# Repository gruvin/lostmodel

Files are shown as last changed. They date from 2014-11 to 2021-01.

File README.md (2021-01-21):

# Open Source RC Lost Model Alarm 
* Two modes -- Normal (manual switch) or Inactivity
* Modes programmable from TX 
* Resonated PIEZO
* LOUD!

Hardware design created in free, open source KiCAD EDA suite.

Employs ATmega88PA (5x5mm MLF) to intelligently drive a quartz piezo via autotransformer at 2.8KHz resonant frequency. This gives air and ear peircingly, LOUD output. Piezo and transformer taken from cheap personal alarm.

The circuit board is 16x33mm and the piezo is 28mm diameter and 3mm thick, including resonance chamber. The autotransformer (11mm height) can be mounted either on the top or bottom of the PCB or off board, if needed for space.

There are three status LEDs. Green, Blue and Red. They do, umm, stuff.

Programming and status tones are emitted (at lower, close range tolerable volume levels!) using Morse code, which I consider better than counting beeps for programming and status reporting.

The alarm can work in either Normal or Inactivity mode.

In Inactivity mode, ear peircing noise is made when there has been no receiver channel activity for a short while. Useful for cases where a dedicated RC channel is not available. Connect to aileron or elevator channel, for example.

Normal mode uses a dedicated receiver channel as a simple on/off switch. (Greater than or lower than mid point.)

## KiCAD v4 PCB Render
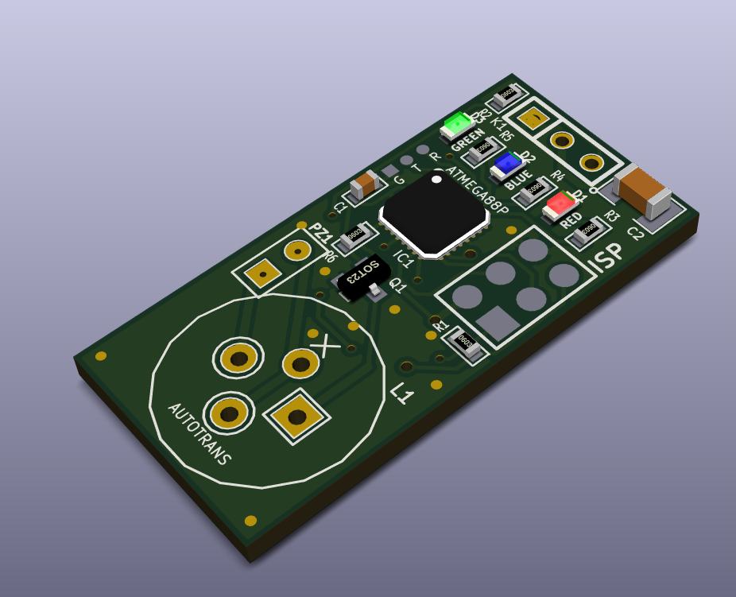
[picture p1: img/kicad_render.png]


Autotransformer and off-board quartz piezo not shown.

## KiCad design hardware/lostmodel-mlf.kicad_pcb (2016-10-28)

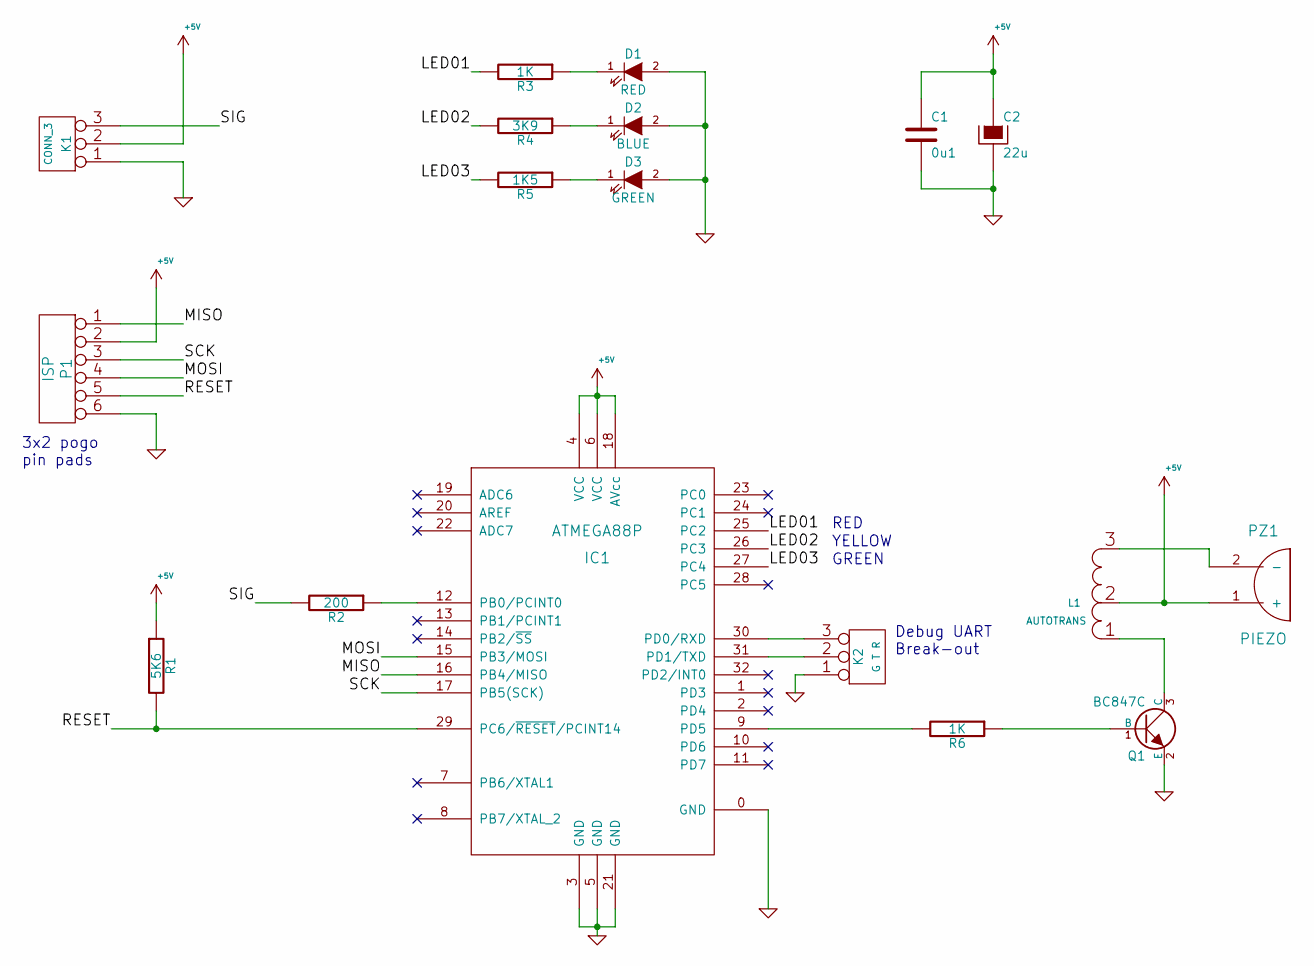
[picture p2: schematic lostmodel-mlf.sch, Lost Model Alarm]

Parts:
C1: 0u1; SM0603_GRUVIN
C2: 22u; SM1210_GRUVIN_POL
D1: RED; LED-0603
D2: BLUE; LED-0603
D3: GREEN; LED-0603
IC1: ATMEGA88P; MLF-32_2mmVIA_SINK
K1: CONN_3; SIL-3
K2: G T R; SIL-3
L1: AUTOTRANS; TRI-3
P1: ISP; PIN_ARRAY_3x2_GRUVIN
PZ1: PIEZO; PIN_ARRAY_2X1
Q1: BC847C; SOT23-BCE
R1: 5K6; SM0603
R2: 200; SM0603
R3, R6: 1K; SM0603
R4: 3K9; SM0603
R5: 1K5; SM0603

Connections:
+5V: C1.1, C2.1, IC1.4 (VCC), IC1.6 (VCC), IC1.18 (AVcc), K1.2 (PM), L1.2, P1.2, PZ1.1 (+), R1.1
/LED01: IC1.25 (PC2), R3.2
/LED02: IC1.26 (PC3), R4.2
/LED03: IC1.27 (PC4), R5.2
/MISO: IC1.16 (PB4/MISO), P1.1
/MOSI: IC1.15 (PB3/MOSI), P1.4
/RESET: IC1.29 (PC6/~RESET~/PCINT14), P1.5, R1.2
/SCK: IC1.17 (PB5(SCK)), P1.3
/SIG: K1.3, R2.2
GND: C1.2, C2.2, D1.2 (A), D2.2 (A), D3.2 (A), IC1.0 (GND), IC1.3 (GND), IC1.5 (GND), IC1.21 (GND), K1.1, K2.1, P1.6, Q1.2 (E)
unnamed: D1.1 (K), R3.1
unnamed: D2.1 (K), R4.1
unnamed: D3.1 (K), R5.1
unnamed: IC1.9 (PD5), R6.2
unnamed: IC1.12 (PB0/PCINT0), R2.1
unnamed: IC1.30 (PD0/RXD), K2.3
unnamed: IC1.31 (PD1/TXD), K2.2 (PM)
unnamed: L1.1, Q1.3 (C)
unnamed: L1.3, PZ1.2 (-)
unnamed: Q1.1 (B), R6.1

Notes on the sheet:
3x2 pogo pin pads
RED
YELLOW
GREEN
Debug UART Break-out

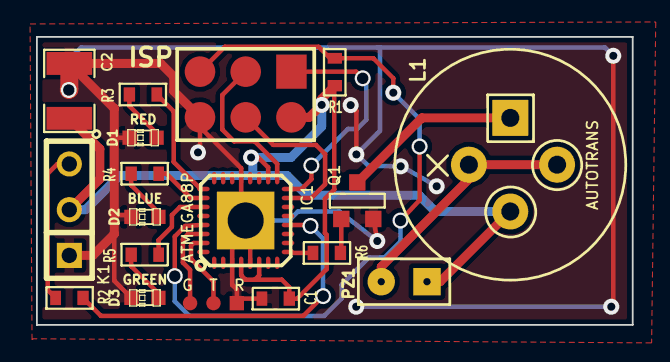
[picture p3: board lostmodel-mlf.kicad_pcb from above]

Board: 2 copper layers, 33.1 x 16.0 mm, 18 parts (0 on the bottom side), 20 nets.

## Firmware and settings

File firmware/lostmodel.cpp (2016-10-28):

/* Filename: lostmodel.cpp
 * Project: Lost Model Alarm for AVR ATmega88P
 * Author: Bryan Rentoul (aka Gruvin)
 * Creation Date: 2014-11-22
 * Tabsize: 2
 * Copyright: (c) 2014 Gruvin9X Project and Bryan J. Rentoul aka Gruvin
 * License: GNU GPL v3 (see License.txt)
 * This Revision: $Id$
 *
 * This file is part of Gruvin9X Lost Model Alarm.
 *
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
 * You should have received a copy of the GNU General Public License
 * along with this program in the file Lincese.txt.  If not, please
 * see <http://www.gnu.org/licenses/>
 */

#include <avr/io.h>
#include <avr/pgmspace.h>
#include <avr/eeprom.h>
#include <avr/wdt.h>
#include <avr/interrupt.h>
#include <util/delay.h>
#include <stdlib.h> // abs()
#include "lostmodel.h"

void beeperOn()
{
  LED_ON(3);

  // PWM ON
  TCCR0A |= (0b10<<COM0B0);
}

void beeperOff()
{
  LED_OFF(3);

  TCCR0A &= ~(0b11<<COM0B0);
}

const unsigned char morseTable[47] PROGMEM = {
  0b11110011, // , ASCII 44(dec)
  0,
  0b11010101, // .
  0b10110010, // /
  0b10111111, // 0
  0b10101111, // 1
  0b10100111, // 2
  0b10100011, // 3
  0b10100001, // 4
  0b10100000, // 5
  0b10110000, // 6
  0b10111000, // 7
  0b10111100, // 8
  0b10111110, // 9
  0,          // :
  0,          // ;
  0,          // <
  0b10110001, // =
  0,          // >
  0b11001100, // ?
  0,          // @
  0b01001000, // A
  0b10010000, // B
  0b10010100, // C
  0b01110000, // D
  0b00100000, // E
  0b10000100, // F
  0b01111000, // G
  0b10000000, // H
  0b01000000, // I
  0b10001110, // J
  0b01110100, // K
  0b10001000, // L
  0b01011000, // M
  0b01010000, // N
  0b01111100, // O
  0b10001100, // P
  0b10011010, // Q
  0b01101000, // R
  0b01100000, // S
  0b00110000, // T
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
}; // morse table


enum morseState_t { 
  END = 0,
  DIT,
  DAH,
  BITGAP,
  LETTERGAP,
  SPACE,
  NEXTBIT,
  NEXTCHAR,
  START,
  STOP
} morseState = STOP;

char *morseString;
// morse for LM - di'dah'di'dit, dah dah (lost model)
static inline void morseStateMachine() 
{
  static unsigned int timer;
  static unsigned char bitCount;
  static unsigned char letterBits;
  static unsigned char charIndex;
  static char thisChar;

  switch (morseState)
  {
    case DIT:
      if (timer == 0)
        beeperOn();
      if (++timer > DITLENGTH) 
      {
        timer = 0;
        morseState = BITGAP;
      }
      break;

    case DAH:
      if (timer == 0)
        beeperOn();
      if (++timer > DITLENGTH * 3)
      {
        timer = 0;
        morseState = BITGAP;
      }
      break;

    case BITGAP:
      if (timer == 0) 
        beeperOff();
      if (++timer > DITLENGTH) morseState = NEXTBIT;
      break;

    case LETTERGAP:
      if (timer == 0) 
        beeperOff();
      if (++timer > DITLENGTH * 2) morseState = NEXTCHAR;
      break;

    case SPACE:
      if (timer == 0) 
        beeperOff();
      if (++timer > DITLENGTH * 6) morseState = NEXTCHAR;
      break;

    case NEXTBIT:

      timer = 0;

      if (letterBits & 0b10000000)
        morseState = DAH;
      else
        morseState = DIT;

      letterBits <<= 1; // shift bits left 1 position
      if (bitCount-- == 0)
        morseState = LETTERGAP;

      break;

    case NEXTCHAR:

      thisChar = pgm_read_byte(&morseString[charIndex++]);

      if (thisChar == ' ') 
      {
        timer = 0;
        morseState = SPACE;
      }
      else if ( (thisChar == '\0') || (thisChar < ',') || (thisChar > 'Z') ) // end of string or invalid character?  
        morseState = STOP;
      else
      {
        letterBits = pgm_read_byte(&morseTable[thisChar-44]);
        bitCount = (letterBits >> 5);
        if (bitCount < 6)
          letterBits <<= 3;
        else
          letterBits <<= 2;

        morseState = NEXTBIT;
      }
      break;


    case START:
      beeperOff();
      timer = 0;
      charIndex = 0;
      morseState = NEXTCHAR;
      break;

    case STOP:
      break; // do nothing

    default:
      morseState = STOP;
      break;

  } // switch
      
}


#define PULSE_INVALID (-1)
volatile int sigPulseWidth;
volatile unsigned int pulseTimeoutCounter = 0;
volatile bool runningIndicatorEnabled = false;
// this ISR called every 250uS
ISR(TIMER2_COMPA_vect)
{
  if (pulseTimeoutCounter++ > PULSE_TIMEOUT)
  {
    sigPulseWidth = PULSE_INVALID;  // signal no pulse detected
    pulseTimeoutCounter--; // prevent counter incrementing further
  }

  static unsigned char count = 0;
  if ((count++ % 4) == 3)  // call the Morse state machine every 1 millisecond 
    morseStateMachine();

  // blink middle (blue) LED briefly, each three seconds to indicate RUNNING state (if so)
  static unsigned int runningIndicatorCount = 0;
  if (runningIndicatorEnabled)
  {
    if (runningIndicatorCount == 0) LED_ON(2);
    else if (runningIndicatorCount == (4 * 120)) LED_OFF(2);  // LED on for 120ms

    if (runningIndicatorCount == (4 * 3000 - 1)) // reset counter at 3 seconds
      runningIndicatorCount = 0;
    else
      runningIndicatorCount++;
  }
  else 
    LED_OFF(2);

}

ISR(TIMER1_CAPT_vect)
{
  // an edge detection event has occured on the ICP1(PB0) pin
  unsigned int icr;

  icr = ICR1; // capture counter value as at this edge trigger

  if (TCCR1B & (1<<ICES1)) // trigger was high going edge
  {
    TCNT1 = 0;             // reset counter
    TCCR1B &= ~(1<<ICES1); // set next trigger to low going edge
  }
  else // trigger was low going edge
  {
    if ((icr > 800) && (icr < 2200)) 
    {
      pulseTimeoutCounter = 0;
      sigPulseWidth = icr;
    }
    else
    {
      sigPulseWidth = PULSE_INVALID; // invalid pulse width
    }
    TCCR1B |= (1<<ICES1); // set next trigger to high going edge
  }

}

void morseStart()
{
  if (morseState != STOP) return;
  morseState = START;
}

void morseStop()
{
  morseState = STOP;
  beeperOff();
}

void storeRunMode(unsigned char newmode)
{
  eeprom_write_byte(0x00, newmode);
}

int main(void)
{
  enum { INIT = 0, WAIT_READY, READY, RUNNING, PROGRAM } runState = INIT;
  enum runMode_t { NORMAL = 0, INACTIVITY } runMode = NORMAL;

  /**************************
   ****  STATE MACHINE   ****
   **************************/
  while (1)
  {

    runningIndicatorEnabled = (runState == RUNNING) ? true : false;
    switch (runState) 
    {
      case INIT: 
      {
        cli();
        wdt_reset();

        wdt_enable(WDTO_4S);  // 4 second watchdog timer. (Brown Out Detector fuses are set for 2.7V)

        LED1_DDR |= (1<<LED1_BIT); LED1_PORT &= ~(1<<LED1_BIT);     // output
        LED2_DDR |= (1<<LED2_BIT); LED2_PORT &= ~(1<<LED2_BIT);     // output
        LED3_DDR |= (1<<LED3_BIT); LED3_PORT &= ~(1<<LED3_BIT);     // output
        PIEZO_DDR |= (1<<PIEZO_BIT); PIEZO_PORT &= ~(1<<PIEZO_BIT); // output (PWM on timer 0)
        SIG_DDR &= ~(1<<SIG_BIT); SIG_PORT |= (1<<SIG_BIT);         // input with pullup (ICR1)

        // set up PWM output on OC0B pin (timer 0)
        TCCR0A = (0b01<<WGM00); // 8-bit Phase Correct PWM mode, output on OC0B (PD5) ...
        TCCR0B = (1<<WGM02) | (0b010<<CS00); // ... clk/8 with TOP(OCR0A)=180 / 2 gives ~2.8KHz

        // start piezo tone out at a lower, quieter frequency and duty cycle
        OCR0A = 255; 
        OCR0B = PWM_DUTY_CYCLE_QUIET;

        // set up timer 1 for input capture compare on ICP1 pin (PB0, IC pin 12)
        TCCR1A = (0b00<<WGM10);
        TCCR1B = (0b010<<CS10); // clk/8 for 1MHz counting
        TCCR1B |= (1<<ICES1);   // trugger on rising edge (initially)
        TCNT1 = 0;
        sigPulseWidth = PULSE_INVALID; 
        TIMSK1 = (1<<ICIE1);    // input capture interrupt enabled

        // set up timer 2 for the Morse code sate machine
        TCCR2A = (0x10<<WGM20); // CTC mode
        TCCR2B = (0b010<<CS20); // CLK / 8 (1Mhz counter rate)
        TCNT2 = 0;
        OCR2A = 249;            // counter TOP (250uS, 8-bit timer)
        TIMSK2 = (1<<OCIE2A);   // enable timer 2 OC interrupt (every 1ms) 
        
        sei(); // gloabl interrupt enable

        // retrieve stored Run Mode from EEPROM
        runMode = (enum runMode_t)eeprom_read_byte(0x00);
        if (runMode > INACTIVITY) // sanitize
        {
          runMode = NORMAL;
          storeRunMode(runMode);
        }

        _delay_ms(1000);             // allow one second for the receiver to boot up
        unsigned int pulseSum = 0;
        unsigned int lastPW = 0;
        int count;
        for (count = 0; count < 10; count++)
        {
          int thisPulse = sigPulseWidth;
          if (lastPW == 0) lastPW = thisPulse;
          if (thisPulse > 0)
          {
            pulseSum += abs(thisPulse - lastPW);
            lastPW = thisPulse;
          }
          _delay_ms(50);
        }
        if ((pulseSum / count) > 200) // enter programming mode if average pulse delta large enough 
        {
          runState = PROGRAM;
          break;
        }
        runState = WAIT_READY;
        break;
      }

      case WAIT_READY: 
      {
        LED_ON(1);

        if ((sigPulseWidth < 0) && (morseState == STOP))
        {
          morseString = (char *)PSTR("E   ");
          morseStart();
        }
        else if (morseState == STOP)
        {
          LED_OFF(1);
          if (runMode == NORMAL)
            morseString = (char *)PSTR("R N ");
          else
            morseString = (char *)PSTR("R I ");
          morseStart();
          runState = READY;
        }
        break;
      }

      case READY:
      {
        if (morseState == STOP)
        {
          // Set beeper frqeuency to ~2.8KHz at 15% duty cycle = LOUD!
          OCR0A = 180;
          OCR0B = PWM_DUTY_CYCLE;

          // emit a single, loud "BIP!"
          if (sigPulseWidth < MIDPOINT)
          {
            beeperOn();
            _delay_ms(100);
            beeperOff();
          }

          runState = RUNNING;
        }
        break;
      }

      case RUNNING: 
      {
        switch (runMode)
        {
          case NORMAL: /* manually switched at transmitter */
          {
            if (sigPulseWidth > 0)
            {
              if (sigPulseWidth > MIDPOINT)
              {
                morseString = (char *)PSTR("LOST "); 
                morseStart();    // start bleeting loud morse tones
              }
              else
                morseStop();
            } 
            else
            {
              morseStop();
              runState = WAIT_READY; // we lost the pulse signal TODO: should optionally alarm instead?
            }
          
            break;
          }

          case INACTIVITY: /* enteres lost mode if no acitivity seen for a while */
          {
            static int last_sigPulseWidth = 0;
            static int last_sigPulseWidthAverage = 0;
            static int sigPulseWidthAverage;
            static unsigned int inactiveTimer = 0;
            
            if (sigPulseWidth > 0) // if pulse has not timed out
            {
              int thisPulse = sigPulseWidth;
              if (last_sigPulseWidth == 0) last_sigPulseWidth = thisPulse;
              sigPulseWidthAverage = ((last_sigPulseWidth * 7) + thisPulse) / 8; // some noise filtering
              last_sigPulseWidth = thisPulse;

              if (last_sigPulseWidthAverage == 0)
                last_sigPulseWidthAverage = sigPulseWidthAverage;

              if ( (sigPulseWidthAverage > (last_sigPulseWidthAverage-20)) 
                  && (sigPulseWidthAverage < (last_sigPulseWidthAverage+20/*TODO sensitivity*/)) )
              {
                if (inactiveTimer++ > 600/*TODO -- how long to wait for inactivity before alarming*/)
                {
                  inactiveTimer--; // don't let this keep climbing
                  if (morseState == STOP)
                  {
                    morseString = (char *)PSTR("LOST "); 
                    morseStart();   // start bleeting loud morse tones
                  }
                }
              }
              else
              {
                inactiveTimer = 0;
                morseStop();
              }
              last_sigPulseWidthAverage = sigPulseWidthAverage;

            }
            else
            {
              morseStop();
              runState = WAIT_READY; // we lost the signal entirely. Go quiet.
            }

          }
        }

        break; // case RUNNING
      }

      case PROGRAM: 
      {
        static enum { 
          WAIT, // wait for pulse to go above MIDPOINT before entering program mode
          ENTER, 
          ASK_NORMAL, 
          ANS_NORMAL, 
          ASK_INACTIVE, 
          ANS_INACTIVE, 
          OK, 
          EXIT 
        } pgmState = WAIT;
        static int pgmTimer = 0;


        switch (pgmState)
        {
          case WAIT:
            if (sigPulseWidth < (MIDPOINT * 1.17)) // at least 3/4 stick needed (allowing for first 1ms being included)
            { 
              if (morseState == STOP)
              {
                LED_TOGGLE(2);
                morseString = (char *)PSTR("W  ");
                morseStart();
              }
            }
            else if (pgmTimer++ > 100)
            {
              pgmTimer = 0;
              morseStop();
              pgmState = ENTER;
            }
            break;

          case ENTER:
            LED_ON(1);
            morseString = (char *)PSTR("P  ");
            morseStart();
            pgmState = ASK_NORMAL;
            break;

          case ASK_NORMAL:
            if (morseState == STOP) // wait for morse code to finish sounding
            {
              pgmTimer = 0;
              morseString = (char *)PSTR("N? ");
              morseStart();
              pgmState = ANS_NORMAL;
            }
            break;

          case ANS_NORMAL:
            if (morseState == STOP) // wait for morse code to finish sounding
            {
              if (pgmTimer++ < 200) // did they say yes?
              {
                if (sigPulseWidth < MIDPOINT)
                {
                  storeRunMode(NORMAL);
                  pgmState = OK;
                }
              } else
                pgmState = ASK_INACTIVE;
            }
            break;

          case ASK_INACTIVE:
            if (morseState == STOP) // wait for morse code to finish sounding
            {
              pgmTimer = 0;
              morseString = (char *)PSTR("I? ");
              morseStart();
              pgmState = ANS_INACTIVE;
            }
            break;

          case ANS_INACTIVE:
            if (morseState == STOP) // wait for morse code to finish sounding
            {
              if (pgmTimer++ < 200) // did they say yes?
              {
                if (sigPulseWidth < MIDPOINT)
                {
                  storeRunMode(INACTIVITY);
                  pgmState = OK;
                }
              } else
                pgmState = ASK_NORMAL;
            }
            break;

          case OK:
            morseString = (char *)PSTR("OK ");
            morseStart();
            pgmState = EXIT;
            break;

          case EXIT:
            if (morseState == STOP) // wait for morse code to finish sounding
              runState = INIT;
            break;
        }

        break;
      }

      default:
        runState = INIT;

    } // FSM switch

    _delay_ms(10); // XXX TODO: fix this ugly hack,  here just to slow down asynch counters for PROGRAM and INACTIVITY modes

    wdt_reset();
  } // MAIN LOOP
}

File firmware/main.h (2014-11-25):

#ifndef _MAIN_H
#define _MAIN_H

#define DEBUG 1

// CW dit length (arbitrary units)
#define DITLENGTH 8 // arbitrary while morseStateMachine is just part of the main loop

// TODO: prototype version. Pins changed for production version ...
//       These are NOT the pins specified in the production electronic schematic
#define SIG_INP   PIND
#define SIG_PORT  PORTD
#define SIG_DDR   DDRD
#define SIG_BIT   3 // D-

#define PIEZO_PORT PORTD
#define PIEZO_DDR  DDRD
#define PIEZO_BIT  5 // LED01

#define LED1_PORT PORTC
#define LED1_DDR  DDRC
#define LED1_BIT  3 // LED05 (not used in prototype)

#define LED2_PORT PORTD
#define LED2_DDR  DDRD
#define LED2_BIT  4 // LED02

#define LED3_PORT PORTC
#define LED3_DDR  DDRC
#define LED3_BIT  5 // LED03

#define LED_ON(a) LED ## a ## _PORT |= (1<<LED ## a ## _BIT)
#define LED_OFF(a) LED ## a ## _PORT &= ~(1<<LED ## a ## _BIT)

// input pulse width measurement
// CLK = 8MHz
// timing loop is 9 cycles
// time for one cycle = 1 / (8,000,000 / 9) = 1.125uS
// 1500uS / 1.125 ~= 1333 
#define MIDPOINT 1350 // value from actual tests

// PWM piezo output volume
#ifdef DEBUG
#define PWM_DUTY_CYCLE 3
#else
#define PWM_DUTY_CYCLE 27
#endif
#define PWM_DUTY_CYCLE_QUIET 2

#define true (-1)
#define false 0

// Run Modes
#define NORMAL 0
#define INACTIVITY 1



#endif

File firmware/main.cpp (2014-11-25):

/* Name: main.c
 * Project: Lost Model Alarm for AVR ATmega88P
 * Author: Bryan Rentoul (aka Gruvin)
 * Creation Date: 2014-11-22
 * Tabsize: 2
 * Copyright: (c) 2014 Gruvin9X Project and Bryan J. Rentoul aka Gruvin
 * License: GNU GPL v2 (see License.txt)
 * This Revision: $Id$
 */

#include <avr/io.h>
#include <avr/pgmspace.h>
#include <avr/eeprom.h>
#include <avr/wdt.h>
#include <util/delay.h>
#include <stdlib.h> // abs()
#include "main.h"

int pulseInWidth()
{
  unsigned int width;         // pulse width in while loop iterations, which should be exactly 10 clock cycles
  unsigned long numloops;
  
  numloops = 0;
  // wait for any previous pulse to end
  while (SIG_INP & (1<<SIG_BIT))
    if (numloops++ > (MIDPOINT * 2)) return -1;

  // wait for pulse to start
  while (!(SIG_INP & (1<<SIG_BIT)))
    if (numloops++ > ((unsigned long)MIDPOINT * 14)) return -1; // MIDPOINT ~= 1500us. Full PPM sweep over 8 channels is 23ms.

  // wait for pulse to end
  width = 0;
  while (SIG_INP & (1<<SIG_BIT))
    if (width++ > (MIDPOINT * 3)) return -1;

  return width; 
}

void beeperOn()
{
  LED_ON(2);

  // PWM ON
  TCCR0A |= (0b10<<COM0B0);
}

void beeperOff()
{
  LED_OFF(2);

  TCCR0A &= ~(0b11<<COM0B0);
}

const char morse[47][7] PROGMEM  = {
  { 2, 2, 1, 1, 2, 2, 0 },// , ASCII = 44
  { 0 },                  // -
  { 1, 2, 1, 2, 1, 2, 0}, // .
  { 2, 1, 1, 2, 1, 0 },   // /
  { 2, 2, 2, 2, 2, 0 },   // 0
  { 1, 2, 2, 2, 2, 0 },   // 1
  { 1, 1, 2, 2, 2, 0 },   // 2
  { 1, 1, 1, 2, 2, 0 },   // 3
  { 1, 1, 1, 1, 2, 0 },   // 4
  { 1, 1, 1, 1, 1, 0 },   // 5
  { 2, 1, 1, 1, 1, 0 },   // 6
  { 2, 2, 1, 1, 1, 0 },   // 7
  { 2, 2, 2, 1, 1, 0 },   // 8
  { 2, 2, 2, 2, 1, 0 },   // 9
  { 0 },                  // :
  { 0 },                  // ;
  { 0 },                  // <
  { 2, 1, 1, 1, 2, 0 },   // =
  { 0 },                  // >
  { 1, 1, 2, 2, 1, 1, 0 },// ?
  { 0 },                  // @
  { 1, 2, 0 },            // A
  { 2, 1, 1, 1, 0 },      // B
  { 2, 1, 2, 1, 0 },      // C
  { 2, 1, 1, 0 },         // D
  { 1, 0 },               // E
  { 1, 1, 2, 1, 0 },      // F
  { 2, 2, 1, 0 },         // G
  { 1, 1, 1, 1, 0 },      // H
  { 1, 1, 0 },            // I
  { 1, 2, 2, 2, 0 },      // J
  { 2, 1, 2, 0 },         // K
  { 1, 2, 1, 1, 0 },      // L
  { 2, 2, 0 },            // M
  { 2, 1, 0 },            // N
  { 2, 2, 2, 0 },         // O
  { 1, 2, 2, 1, 0 },      // P
  { 2, 2, 1, 2, 0 },      // Q
  { 1, 2, 1, 0 },         // R
  { 1, 1, 1, 0 },         // S
  { 2, 0 },               // T
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
}; // morse table


enum morseState_t { 
  END = 0,
  DIT,
  DAH,
  BITGAP,
  LETTERGAP,
  SPACE,
  NEXTBIT,
  NEXTCHAR,
  START,
  STOP
} morseState = STOP;

char *morseString;
// morse for LM - di'dah'di'dit, dah dah (lost model)
void morseStateMachine()
{
  static unsigned int timer;
  static unsigned char bitIndex;
  static unsigned char charIndex;
  static char thisChar;

  switch (morseState)
  {
    case DIT:
      if (timer == 0)
        beeperOn();
      if (++timer > DITLENGTH) 
      {
        timer = 0;
        morseState = BITGAP;
      }
      break;

    case DAH:
      if (timer == 0)
        beeperOn();
      if (++timer > DITLENGTH * 3)
      {
        timer = 0;
        morseState = BITGAP;
      }
      break;

    case BITGAP:
      if (timer == 0) 
        beeperOff();
      if (++timer > DITLENGTH) morseState = NEXTBIT;
      break;

    case LETTERGAP:
      if (timer == 0) 
        beeperOff();
      if (++timer > DITLENGTH * 2) morseState = NEXTCHAR;
      break;

    case SPACE:
      if (timer == 0) 
        beeperOff();
      if (++timer > DITLENGTH * 6) morseState = NEXTCHAR;
      break;

    case NEXTBIT:

      timer = 0;

      morseState = (morseState_t)pgm_read_byte(&morse[thisChar-44][bitIndex++]);

      if ((morseState == END) || (bitIndex > sizeof(morse[1]))) {
        morseState = LETTERGAP;
        bitIndex = 0;
      };

      break;

    case NEXTCHAR:

      thisChar = pgm_read_byte(&morseString[charIndex++]);

      if (thisChar == ' ') 
      {
        timer = 0;
        morseState = SPACE;
      }
      else if ((thisChar == '\0') || (thisChar < ',') || (thisChar > 'Z'))
        morseState = STOP;
      else
        morseState = NEXTBIT;

      break;


    case START:
      beeperOff();
      timer = 0;
      bitIndex = 0;
      charIndex = 0;
      morseState = NEXTCHAR;
      break;

    case STOP:
      beeperOff();
      break; // do nothing

    default:
      morseState = STOP;
      break;

  } // switch
      
}

void morseStart()
{
  if (morseState != STOP) return;
  morseState = START;
}

void morseStop()
{
  morseState = STOP;
  beeperOff();
}

void setRunMode(unsigned char newmode)
{
  eeprom_write_byte(0x00, newmode);
}
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

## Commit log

2014-11-24 Version 1.0 final
    [lostmodel-mlf.brd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]
2014-11-24 r3 production files frozen
    [lostmodel-mlf-B_Cu.gbl, lostmodel-mlf-B_Mask.gbs, lostmodel-mlf-B_SilkS.gbo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]
2014-11-25 Fixed the Makefile I broke -- I hope. Make is so damned confusing! :-(
    [main.h]
2014-11-26 object name changes and fixed compile options to give dissasembly for main() (objdump bug workaround)
    [lostmodel.cpp, lostmodel.h]
2014-11-26 License text (again -- boring!) and some refactoring ... including putting the Morse state machine on a timer interrupt instead of the main loop.
2014-11-26 Getting ready for new PCBs and hardware pulse width counting using timer 1 ICP1(PB0) pin.
2014-11-27 fixed WDT/BOR reset logic
    [lostmodel.cpp]
2014-11-28 Added UART break-out to PCB for possible future debug (or other) use.
    [lostmodel-mlf.brd, lostmodel-mlf.sch]
2014-11-28 PCB v1.1 tidying after Gerber view check.
    [lostmodel-mlf.brd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]
2016-10-28 Revision v1.2 including KiCAD upgrade
    [lostmodel-mlf.kicad_pcb]
2016-10-28 Added a KiCAD PCB render image
2016-10-28 Completing KiCAD upgrade changes
    [lostmodel-mlf.brd, lostmodel-mlf.kicad_pcb, lostmodel-mlf.sch]

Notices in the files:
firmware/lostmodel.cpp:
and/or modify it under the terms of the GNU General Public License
